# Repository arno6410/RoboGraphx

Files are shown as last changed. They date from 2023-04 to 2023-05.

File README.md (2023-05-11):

# RoboGraphx
The goal of this project is to develop a system that can write and erase on a blackboard, and draw some basic figures. The inspiration for the design/working is the [Maslow CNC](https://www.maslowcnc.com/)

## Usage/Examples

Right now, the system can draw most Gcode on a whiteboard

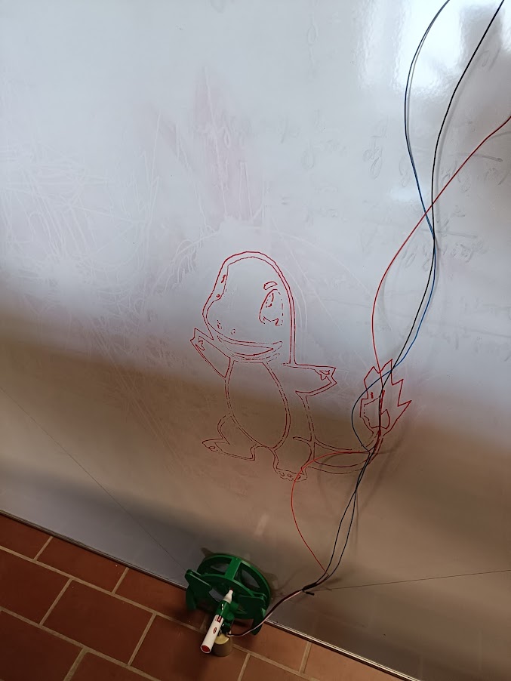
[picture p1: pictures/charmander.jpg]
example


Supported commands: 
- **G... X... Y... F...**
    - **G** determines the command type
        - **G0** is a travel move (no writing)
        - **G1** is a writing move
        - **G90** specifies that the following coordinates will be absolute to the system origin
        - **G91** is the same but for relative coordinates
        - **G28** is a homing command, resetting the system to the start position
    - **X** and **Y** determine the target X and Y coordinates
    - **F** sets the stepper motor speed [steps/second]
- **M5** and **M3 S255**
    - **M5** engages the servo such that the pen is touching the whiteboard
    - **M3 S255** disengages the pen
- **A...,...**
    - To set the X and Y board positions
    - Automatically generated by the Python GUI code

The best way to generate usable Gcode is to convert a SVG to Gcode using [Inkscape](https://inkscape.org/) and the [J Tech Photonics Laser Tool](https://github.com/JTechPhotonics/J-Tech-Photonics-Laser-Tool) extension

Right now, there is no calibration procedure. The sled with the marker has to be placed at the bottom in the middle of the width of the board before starting. After a drawing, the sled will automatically return to this 'home' position

## Installation

### Electronics
The following circuit has to be made twice, once for each stepper motor
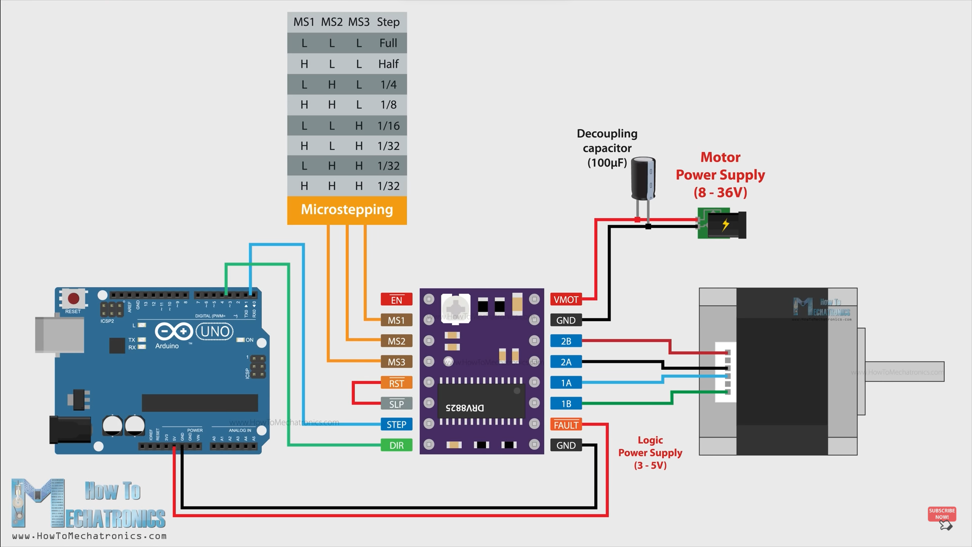
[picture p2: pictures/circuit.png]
circuit

[Source](https://howtomechatronics.com/tutorials/arduino/stepper-motors-and-arduino-the-ultimate-guide/).
The pins on the arduino can be found in the arduino code, they can also be changed there if desired. The source voltage should be +12V and gnd. The breadboard connections look like this:
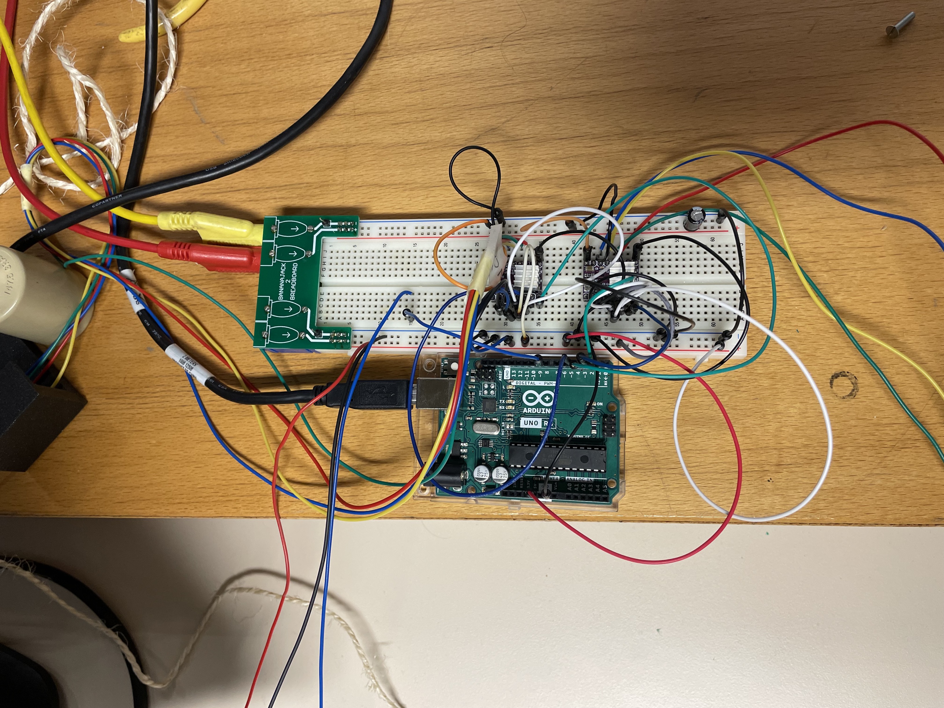
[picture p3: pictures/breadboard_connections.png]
bread

For controlling the pen, a servo motor is used. The to be connected pins can also be found in the arduino code. It should be connected to +5V, gnd and the correct data pin on the arduino. 

Parts list:
 - Arduino Uno
 - NEMA 17 stepper motor
 - DRV8825 Stepper Motor Controller
 - Decoupling capacitor
 - Any generic servo motor
 - Some wires

Almost all these parts are interchangable with similar parts
### Arduino code
The arduino never has to be touched while running RoboGraphx. Everything can be configured from the Python GUI. The arduino code just has to be uploaded to the device. The constants in the arduino code can be found on following diagram:
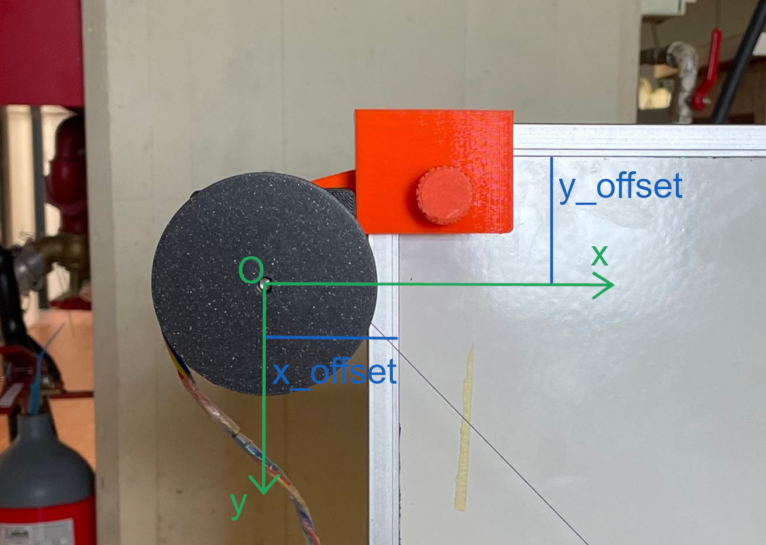
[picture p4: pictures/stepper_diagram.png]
diagram

### Python code
Running the Python code gives a simple GUI to start drawing. It is connected to the arduino via a USB cable, using the UART protocol. The Python code sends the Gcode line by line to the arduino, which then parses each command and controls the stepper motors.The SERIAL_PORT has to be changed depending on the computer that runs the code
### 3D printed parts
All the other parts can be 3D printed, the files are found in the '3d models' folder
### Making suitable Gcode
[This](./documents/gcode-guide.pdf) pdf explains the process to convert any image to usable Gcode using Inkscape
## Possible Future Features

- Improving the workflow
    - One program / GUI to convert images to Gcode and also to draw the Gcode
- Clean up the setup (Better cables, make a PCB, ...)
- Calibration procedure to automatically determine board dimensions/position
- Automatically erase the board
- Typing text into the GUI -> Gcode -> writing on the board
    - Some default drawings, eg. writing 'Smith Chart' will draw a smith chart
- Make the signals to arduino wireless (Bluetooth/Wifi)

## Sources
https://howtomechatronics.com/tutorials/arduino/stepper-motors-and-arduino-the-ultimate-guide/
https://forums.maslowcnc.com/t/chain-length-calculations/6029

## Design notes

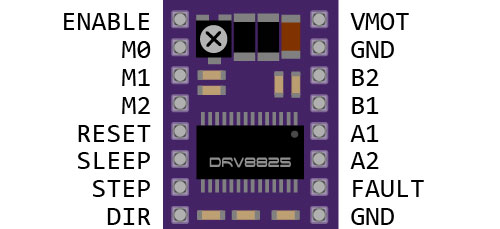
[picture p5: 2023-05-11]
pictures/driver.png

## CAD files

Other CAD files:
3d models/Bracket v2.f3d
3d models/SLED v13.f3d

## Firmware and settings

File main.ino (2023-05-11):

/*
    Controlling two stepper with the AccelStepper library

     by Dejan, https://howtomechatronics.com
*/

#include <AccelStepper.h>
#include <MultiStepper.h>
#include "Sled.h"
#include <math.h>
#include <Servo.h>

// use 1/16 steps! 200 steps per revolution -> 3200 steps per revolution
// This is defined in rotation_size
// Origin in upper left corner

// Define the stepper motor and the pins that is connected to
AccelStepper stepper1(1, 5, 4);  // (Typeof driver: with 2 pins, STEP, DIR)
AccelStepper stepper2(1, 3, 2);
MultiStepper steppers_control;  // Create instance of MultiStepper
long go_to_position[2];         // An array to store the target position (x and y coordinates)
unsigned long t1;
unsigned long t2;
unsigned long myTime;
int rotation_size = 3200;       // 1/16 Microstepping, amount of steps for one rotation of stepper motor
float x_offset = 8 + 21;          // AFSTAND TUSSEN STEPPER AS EN BORD, 8mm rand + 21 mm naar as van stepper
float y_offset = 30;              // bocenkant bord naar stepper
float ground_to_pen = 120;        //offset tussen grond en de pen
float radius = 15;              // [mm]
float x_board = 2400;            // [mm]
float y_board = 1200;           // [mm]
float x_start = x_board/2 + x_offset;   // [mm]
float y_start = y_board-y_offset-ground_to_pen;            // [mm]

Sled krijtje(x_start, y_start, x_board + 2*x_offset, y_board, radius, rotation_size);  //Create sled object
bool movement_type = false;     // false if absolute movement, true if relative movement

Servo myservo;
int servo_pos = 0;    // variable to store the servo position

void setup() {
  stepper1.setMaxSpeed(500);       // Set maximum speed value for the stepper
  stepper1.setCurrentPosition(0);  // Set the current position to 0 steps

  stepper2.setMaxSpeed(500);       // Set maximum speed value for the stepper
  stepper2.setCurrentPosition(0);  // Set the current position to 0 steps

  steppers_control.addStepper(stepper1);  //Add both steppers to MultiStepper object;
  steppers_control.addStepper(stepper2);

  Serial.begin(9600);  //9600 baud rate
  Serial.setTimeout(10);

  myservo.attach(9);
  servo_pos = myservo.read();

  Serial.println("-----------------------");
}

void loop() {

  if (Serial.available() > 0) {
    long int t3 = millis();
    String received_command = Serial.readString();
    long int t4 = millis();
    received_command.trim();
    Serial.println(received_command);
    Serial.print("Time taken by reading serial: "); Serial.print(t4-t3); Serial.println(" milliseconds");

    long int t1 = millis();
    InterpretGCode(received_command);
    long int t2 = millis();
    Serial.print("Time taken by InterpretGCode: "); Serial.print(t2-t1); Serial.println(" milliseconds");
  }
}


// ====================Functions====================
void MoveStraight(float x_destination, float y_destination, MultiStepper steppers_control, bool coordinate_type) { 
  // Steppers are moved to destination
  // X and Y coordinates, MultiStepper object, coordinate_type to set relative or absolute movement
  // coordinate_type false for absolute movement, true for relative movement
  long go_to_position[2];

  Serial.print("X: ");
  Serial.print(x_destination);
  Serial.print(", Y: ");
  Serial.println(y_destination);
  if(coordinate_type == true){ // When relative movement, update the coordinates
    x_destination = x_destination + krijtje.GetXPosition();
    y_destination = y_destination + krijtje.GetYPosition();
  }

  // Check boundaries of board AFWERKEN
  if(x_destination >  x_board + 2 * x_offset){
    x_destination =  x_board - 2 * x_offset;
  } else if (x_destination < 0){
    x_destination = 2*x_offset;
  }
  if(y_destination >  y_board){
    y_destination =  y_board;
  } else if (y_destination < 0){
    y_destination = 50;
  }

  // Calculate number of steps steppers need to move
  krijtje.Update(x_destination, y_destination);
  long steps1 = krijtje.CalculateSteps(1);
  Serial.print("steps1: ");
  Serial.print(steps1);
  long steps2 = krijtje.CalculateSteps(2);
  Serial.print(", steps2: ");
  Serial.println(steps2);

  go_to_position[0] = steps1;
  go_to_position[1] = steps2;

  steppers_control.moveTo(go_to_position);
  steppers_control.runSpeedToPosition();

  //Stepper position reset to 0 so that they move again next round
  stepper1.setCurrentPosition(0);
  stepper2.setCurrentPosition(0);

  //Set the internal stepper position to the destination. Currently no calibration/FB so the object needs to remember its position
  krijtje.SetPosition(x_destination, y_destination);

}

void InterpretGCode(String command){
  // command is a single line of G-code, function interprets it and acts according to the command
  // In the form: G01 X200 Y300

  float x_coord;          // X and Y coordinates
  float y_coord;
  bool move = false;      // Set to true if the Gcommand is for moving (G0, G1)
  int speed = 1000;
  int home_speed = 3000;
  int m_value = 0;
  bool is_writing = false;//Necessary?
  int pos = 0;

  //Seperate command string into array of parameters
  do {
    int i1 = command.indexOf(' ');    // Takes index of space character in string

    String next_parameter = command.substring(0, i1); // Next parameter to consider is everything until the space
    Serial.println(next_parameter[0]);
    switch(next_parameter[0]){
      case 'X':
      {
        Serial.println("X command");
        x_coord = next_parameter.substring(1).toFloat();
        break;
      }
      case 'Y':
      {
        Serial.println("Y command");
        y_coord = next_parameter.substring(1).toFloat();
        break;
      }
      case 'A':
      {
        Serial.println("A command");
        String test_command = next_parameter.substring(1);
        // command.substring(i1);    // Only keeps the substring of the string after index i1
        // test_command.trim();
        int i2 = test_command.indexOf(',');
        // String test_parameter = test_command.substring(0, i2);
        
        x_board = test_command.substring(0, i2).toFloat();
        Serial.print("X board: ");
        Serial.println(x_board);
        
        // int i2 = test_command.indexOf(' ');
        // String test_parameter = test_command.substring(0, i2);
        y_board = test_command.substring(i2+1).toFloat();
        Serial.print("Y board: ");
        Serial.println(y_board);
        krijtje.SetBoardSize(x_board, y_board, x_offset, y_offset, ground_to_pen);

        x_start = x_board/2 + x_offset;
        y_start = y_board-y_offset-ground_to_pen;
        krijtje.SetPosition(x_start, y_start); // reset starting position to middle bottom of board

        Serial.print("X board updated: ");
        Serial.println(krijtje.GetXBoard());

        Serial.print("Start position: X = ");
        Serial.print(krijtje.GetXPosition());
        Serial.print(", Y = ");
        Serial.println(krijtje.GetYPosition());
        break;
      }
      case 'F':
      {
        Serial.println("F command");        
        speed = next_parameter.substring(1).toInt();
        stepper1.setMaxSpeed(speed);
        stepper2.setMaxSpeed(speed);
        Serial.print("Set speed to: ");
        Serial.println(speed);
        break;
      }
      case 'M':
      {
        Serial.println("Engage pen");
        m_value = next_parameter.substring(1).toInt();
        if (m_value == 3){
          for (pos = servo_pos+50; pos >= servo_pos; pos -= 1) { // goes from 180 degrees to 0 degrees
            myservo.write(pos);              // tell servo to go to position in variable 'pos'
            delay(1);                       // waits 15ms for the servo to reach the position
          }
          // myservo.write(0);
          // myservo.write(90);
        }
        else if (m_value == 5){
          

          for (pos = servo_pos; pos <= servo_pos+30; pos += 1) { // goes from 0 degrees to 10 degrees
            // in steps of 1 degree
            myservo.write(pos);              // tell servo to go to position in variable 'pos'
            delay(1);                       // waits 15ms for the servo to reach the position
          }
        }
        break;
      }
      case 'G':     
      {
        Serial.println("G command");
        int command_type = next_parameter.substring(1).toInt(); // Take the int after G
        if (command_type == 0){   // Travel move (marker / chalk not engaged)
          move = true;
        }
        else if (command_type == 1){    // Draw move
          move = true;
        }
        else if (command_type == 90){   // Absolute
          movement_type = false;
        }
        else if (command_type == 91){   // Relative
          movement_type = true;
        }
        else if(command_type == 28){    // Homing
          x_coord = x_start;
          y_coord = y_start;


          stepper1.setMaxSpeed(home_speed);
          stepper2.setMaxSpeed(home_speed);          

          for (pos = servo_pos; pos <= servo_pos+30; pos += 1) { // goes from 0 degrees to 10 degrees
            // in steps of 1 degree
            myservo.write(pos);              // tell servo to go to position in variable 'pos'
            delay(1);                       // waits 15ms for the servo to reach the position
          }
          move = true;
        }
        break;
      }
      default:
      {
        Serial.println("defa");
        break;
      }      
    }

    command = command.substring(i1);    // Only keeps the substring of the string after index i1
    command.trim();
  } while(command != "");   // While loop until string is empty

  Serial.println(move);
  if(move == true){
    MoveStraight(x_coord, y_coord, steppers_control, movement_type);
    Serial.println("movement finished");
  }

  Serial.println("ok");   // This is needed for the UART communication with Python
}

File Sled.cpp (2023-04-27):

// Sled.cpp
#include "Sled.h"
#include <math.h>

Sled::Sled(float x_start, float y_start, float x_board, float y_board, float r, int rsize){
  // _x_position = x_start;
  // _y_position = y_start;
  Sled::SetPosition(x_start, y_start);
  _x_board = x_board;
  _y_board = y_board;
  _radius = r;
  _rotation_size = rsize;
  
  _d1A = 0;
  _d1B = 0;
  _d2A = 0;
  _d2B = 0;
}

float Sled::CalculateRopeLength(float point_x, float point_y, int stepper_number){ //Calculate length of rope from spool to one point
  float stepper_x;
  if(stepper_number == 1){
    stepper_x = 0;
  }
  else{
    stepper_x = _x_board;
  }
  float stepper_y = 0;

  float stepper_distance_straight = sqrt(pow((point_x-stepper_x),2)+pow((point_y),2));    //[mm]

  float a = asin((point_y)/stepper_distance_straight);                
  float b = asin((_radius/stepper_distance_straight));
  float rope_angle = a + b;

  float rope_around_spool = rope_angle * _radius;   //[mm]                                       
  float rope_straight = sqrt(pow(stepper_distance_straight,2) - pow(_radius,2));    //[mm]
  float rope_length = rope_around_spool + rope_straight;    //[mm]

  return rope_length;
}

void Sled::Update(float x_destination, float y_destination){ //efficienter maken
  // Serial.print("Updating sled position to ");
  // Serial.print(x_destination);
  // Serial.print(", ");
  // Serial.println(y_destination);


  _d1A = Sled::CalculateRopeLength(_x_position, _y_position, 1);
  // Serial.print("d1A: ");
  // Serial.print(_d1A);
  _d1B = Sled::CalculateRopeLength(x_destination, y_destination, 1);
  // Serial.print(", d1B: ");
  // Serial.print(_d1B);
  _d2A = Sled::CalculateRopeLength(_x_position, _y_position, 2);
  // Serial.print(", d2A: ");
  // Serial.print(_d2A);
  _d2B = Sled::CalculateRopeLength(x_destination, y_destination, 2);
  // Serial.print(", d2B: ");
  // Serial.println(_d2B);

  // DEBUG: print updated lengths
  Serial.print("Rope lengths: d1A = ");
  Serial.print(_d1A);
  Serial.print(", d1B = ");
  Serial.print(_d1B);
  Serial.print(", d2A = ");
  Serial.print(_d2A);
  Serial.print(", d2B = ");
  Serial.println(_d2B);
}

long Sled::CalculateSteps(int stepper_number){
  float steps_float;
  if(stepper_number == 1){
    steps_float = (_d1A-_d1B)*_rotation_size/(2*M_PI*_radius); //Omgedraaid omdat ze niet in de juiste richting draaiden
  }
  else{
    steps_float = (_d2B-_d2A)*_rotation_size/(2*M_PI*_radius);
  }
  
  long steps = (long) steps_float;
  return steps;
}

void Sled::SetPosition(float new_x, float new_y){
  _x_position = new_x;
  _y_position = new_y;
}

void Sled::SetBoardSize(float x_board, float y_board, float x_offset, float y_offset, float ground_to_pen){
  _x_board = x_board + 2*x_offset;
  _y_board = y_board - y_offset;
  Sled::SetPosition(_x_board/2, _y_board - ground_to_pen);
}

float Sled::GetXPosition(){
  return this->_x_position;
}

float Sled::GetYPosition(){
  return this->_y_position;
}

float Sled::GetXBoard(){
  return _x_board;
}

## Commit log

2023-04-05 Drawing from Gcode
    some bugs
    [main.ino]
2023-04-21 GUI + Servo to move the pen on and off the board
2023-04-26 Rare bug bij switch case
    [Sled.cpp, main.ino]
2023-04-27 Added {} in the switch case
2023-04-27 SEMI WERKENDE DYNAMIC BOARD SIZE
2023-05-03 Drawing / Servo works
2023-05-11 Final commit
    [Bracket v2.f3d, SLED v13.f3d]
